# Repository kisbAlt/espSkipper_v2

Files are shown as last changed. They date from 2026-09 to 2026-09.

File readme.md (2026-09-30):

 <div align="center">
  <picture>
    <source media="(prefers-color-scheme: dark)" srcset="./documentation/logo_dark.png">
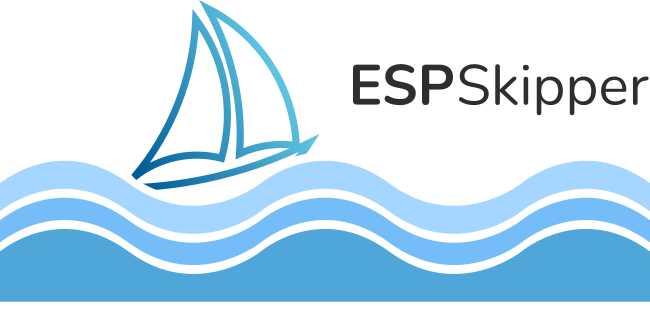
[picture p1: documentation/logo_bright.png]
ESP Skipper logo
    
  </picture>
  <h2 align="center">ESP32 Boat Instrument</h2>
</div>

## ESPSkipper

ESP32 based, open source, low cost boat instrumentation to replace proprietary marine systems.

## Features

- GPS based speed display
- Dynamic multi-function display showing real-time metrics
- Using ST7306 300x400 reflective for good outdoors visibility with custom illumination
- Multi language support
- Configuration through settings page
- Open Echo integration, supports depth readings from the TUSS4470 shield through serial connection
- Rugged 3D printed weather-resistant housing
- Reading water temp thermistors from analog transducers

## Tech Stack

**ESP32:** C++, PlatformIO, Arduino Platform, KiCad  

## Custom PCB

You can find the custom PCB files for KiCad in the hardware folder.

<div align="center" style="display: flex; justify-content: center; align-items: center; gap: 16px; flex-wrap: wrap;">
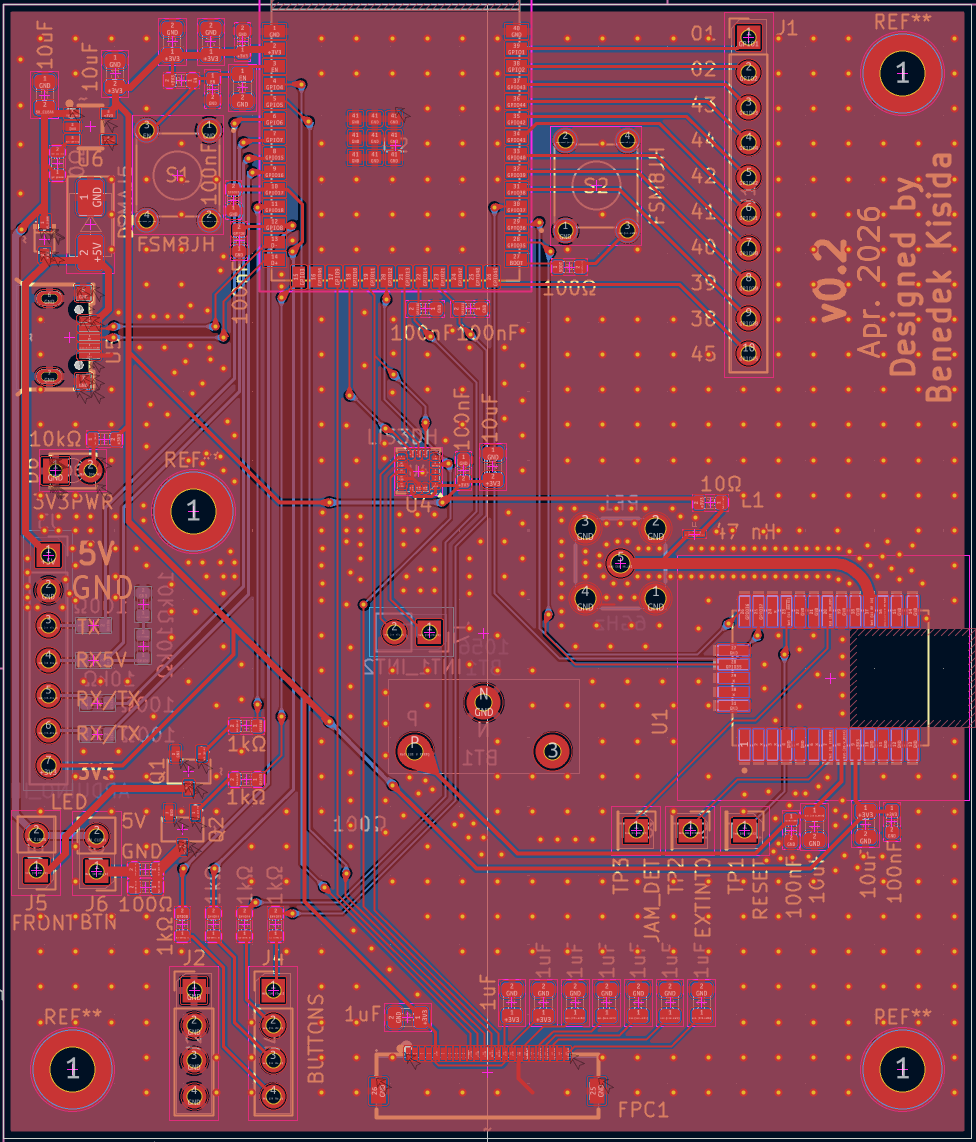
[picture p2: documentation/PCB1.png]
PCB front view
  
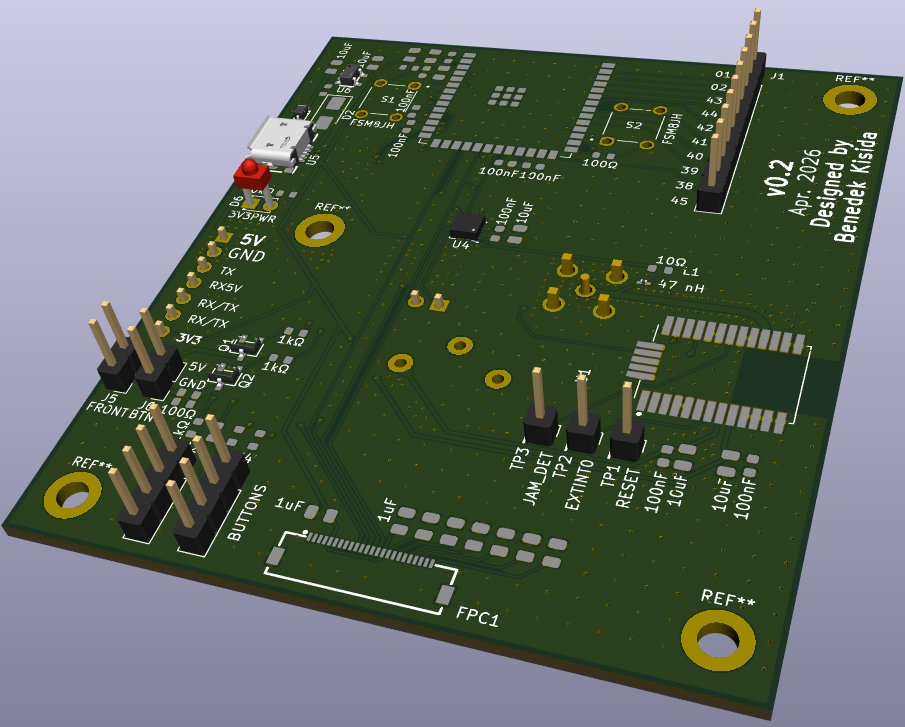
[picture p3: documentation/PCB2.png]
PCB rear view
  
</div>

### ESP32-S3 pinout:

| Module | Signal | GPIO | Notes |
|---|---|---:|---|
| Display / LIS3DH | LCD_SCLK / SPC | GPIO12 | Shared clock for both devices |
| Display / LIS3DH | LCD_SDI / SDO / MOSI | GPIO11 | Shared data output |
| Display / LIS3DH | SDI / MISO | GPIO13 | Shared data input; ignored for LCD |
| LIS3DH | CS | GPIO10 | Dedicated chip select for device 1 |
| Display (PCB variant) | LCD_RES | GPIO4 | Alternate board mapping |
| Display (PCB variant) | LCD_D/C | GPIO9 | Alternate board mapping |
| Display (PCB variant) | LCD_CS | GPIO5 | Alternate board mapping |
| Display (PCB variant) | LCD_SCLK | GPIO12 | Alternate board mapping |
| Display (PCB variant) | LCD_SDI | GPIO11 | Alternate board mapping |
| LIS3DH (PCB variant) | SDO | GPIO13 | Alternate board mapping |
| LIS3DH (PCB variant) | SDI | GPIO11 | Alternate board mapping |
| LIS3DH (PCB variant) | SPC | GPIO12 | Alternate board mapping |
| LIS3DH (PCB variant) | CS | GPIO10 | Alternate board mapping |
| GNSS (L96-M33) | RX0 | GPIO36 | GPS receiver input |
| GNSS (L96-M33) | TX0 | GPIO37 | GPS receiver output |
| GNSS (L96-M33) | FORCE_ON | GPIO35 | Module power control |
| Serial | TX1 | GPIO6 | Serial port 1 output |
| Serial | RX1 | GPIO7 | Serial port 1 input |
| Serial | TX2 | GPIO15 | Serial port 2 output |
| Serial | RX2 | GPIO16 | Serial port 2 input |
| Buttons | BTN1 | GPIO21 | Front panel button |
| Buttons | BTN2 | GPIO14 | Front panel button |
| Buttons | BTN3 | GPIO3 | Front panel button |
| Buttons | BTN4 | GPIO8 | Front panel button |

## Instrument housing

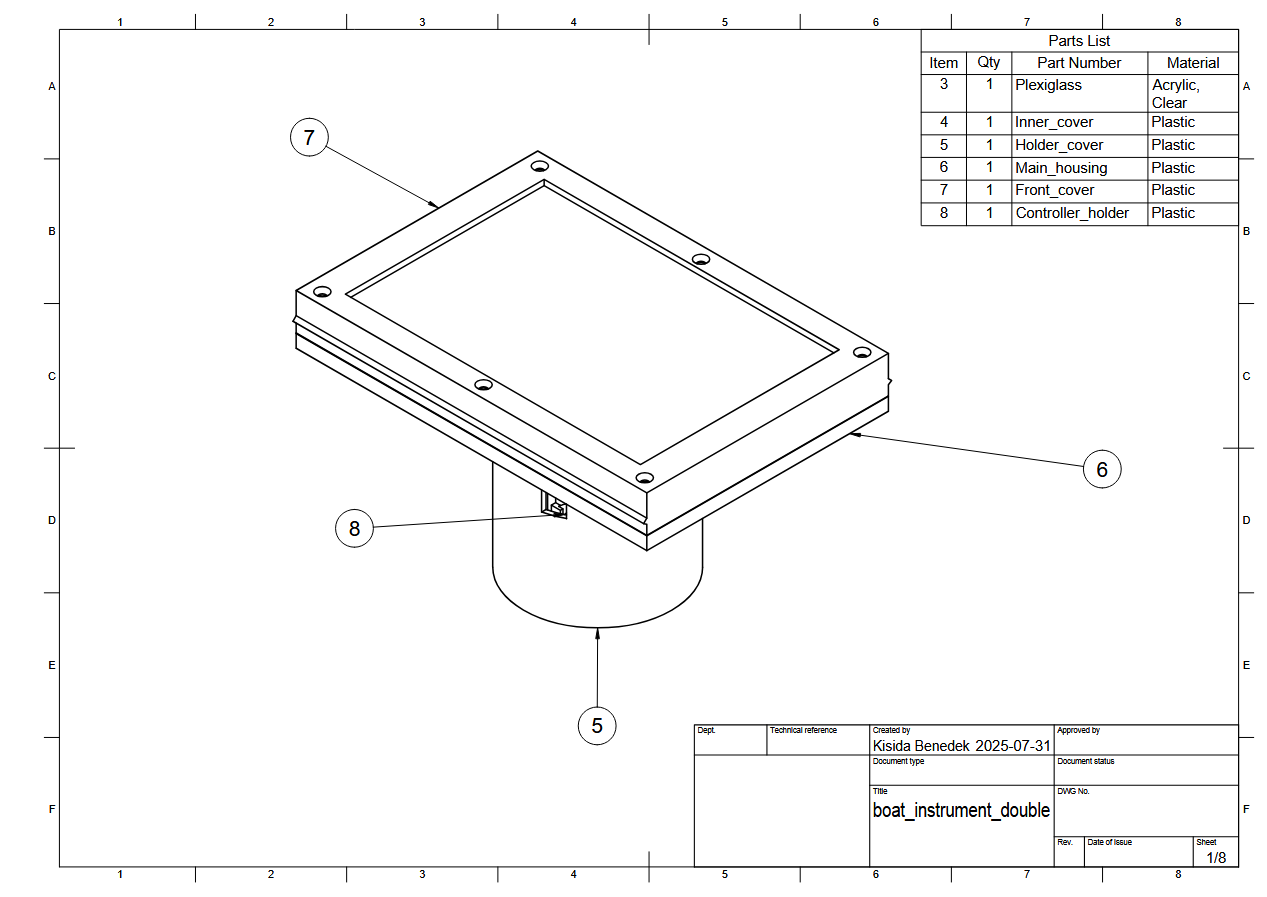
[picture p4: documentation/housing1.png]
Housing1

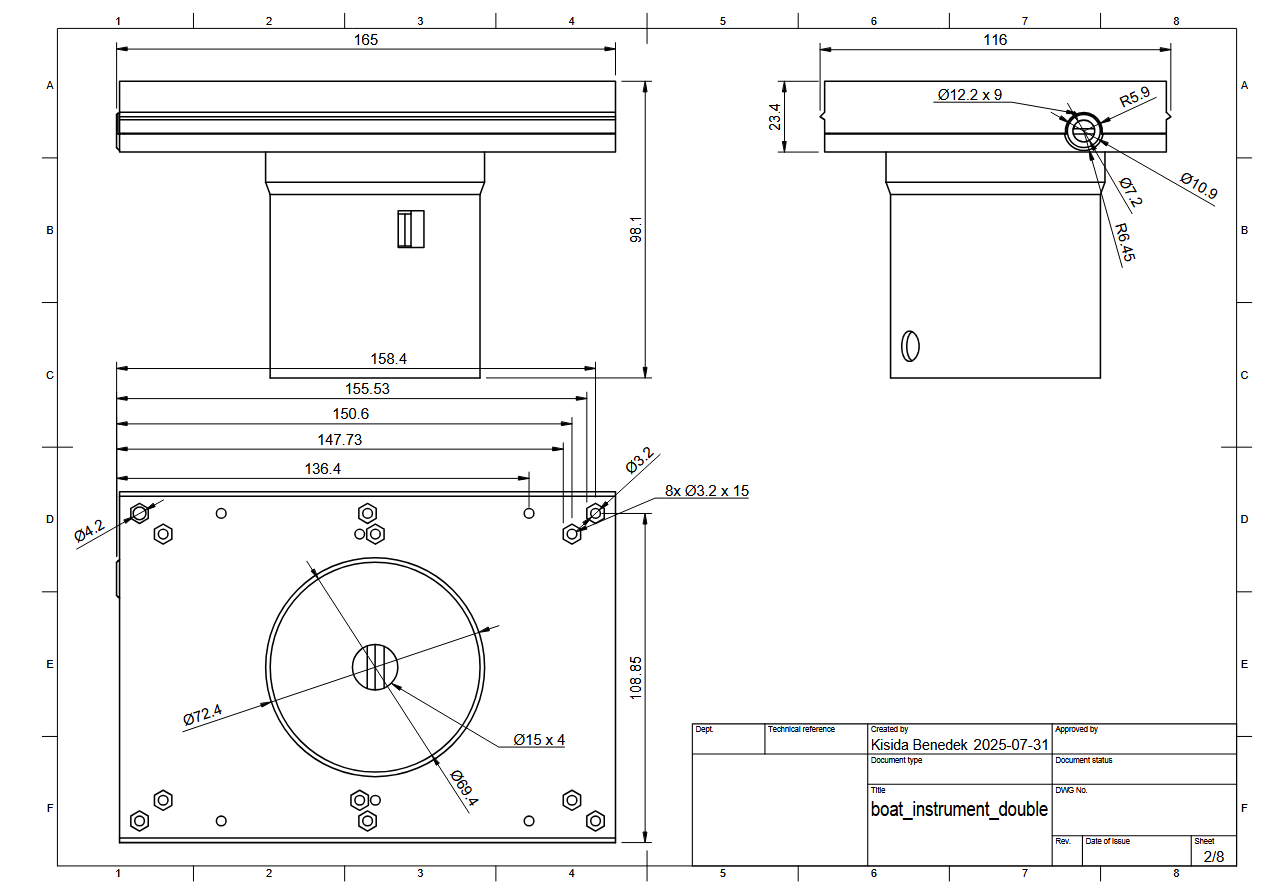
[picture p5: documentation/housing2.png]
Housing2


## PCB Bill of Materials (BOM)

| Ref | Qty | Value | Notes |
|---|---:|---|---|
| U2 | 1 | ESP32-S3-WROOM-1 | Main MCU |
| U1 | 1 | L96-M33 | GNSS module |
| U4 | 1 | LIS3DH | Accelerometer |
| U5 | 1 | - | Micro USB connector |
| U6 | 1 | - | 3.3V regulator |
| BT1 | 1 | 1056 | Battery holder |
| RF1 | 1 | 6GHz | SMA antenna connector |
| FPC1 | 1 | - | Flex cable connector |
| S1, S2 | 2 | FSM8JH | Tactile switches |
| J1 | 1 | Conn_01x10_Pin | 10-pin header |
| J2, J4 | 2 | Conn_01x04_Pin | 4-pin header |
| J3 | 1 | ARDUINO_IN | Arduino interface header |
| J5, J6 | 2 | Conn_01x02_Pin | 2-pin header |
| J7 | 1 | INT1_INT2 | Interrupt header |
| D2 | 1 | SMAJ5 | TVS diode |
| D1 | 1 | - | Schottky diode |
| D6 | 1 | 3V3PWR | 3.3V power LED |
| Q1, Q2 | 2 | - | S8050 transistor pair |
| L1 | 1 | 47 nH | Inductor |
| C1, C2, C3, C4, C16, C18, C20 | 7 | 10uF | Decoupling capacitor |
| C6, C22, C23, C24, C25, C26, C27, C28, C29 | 9 | 1uF | Filter / bulk capacitor |
| C5, C7, C8, C9, C10, C11, C17, C19, C21 | 9 | 100nF | Decoupling capacitor |
| R1, R7, R8, R9, R18, R19 | 6 | 100Ω | Current / pull-up resistor |
| R10, R11, R12, R13, R16, R17 | 6 | 1kΩ | LED / logic resistor |
| R3, R4, R5, R6, R14 | 5 | 10kΩ | Pull-up / bias resistor |
| R2 | 1 | 10Ω | Series resistor |
| R15 | 1 | 0Ω | Link / jumper resistor |
| TP1 | 1 | RESET | Test point |
| TP2 | 1 | EXTINT0 | Test point |
| TP3 | 1 | JAM_DET | Test point |

## Acknowledgements

 - [Open Echo](https://github.com/Neumi/open_echo)
 - [Osptek 4.2" BWR TFT Driver for ESP32-S3 (ST7306)](https://github.com/CaiZiYuan2019/Osptek-4.2-BWR-TFT-Driver-for-ESP32-S3)

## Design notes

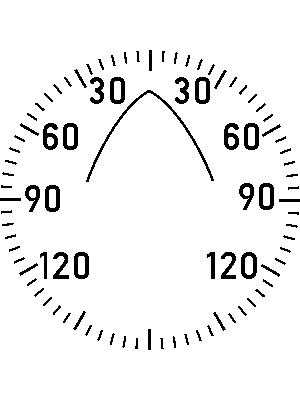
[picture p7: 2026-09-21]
img/wind_gimp.png

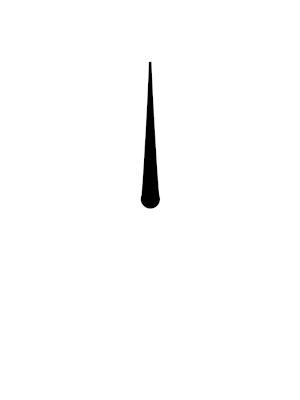
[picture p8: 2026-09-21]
img/wind_hand.png

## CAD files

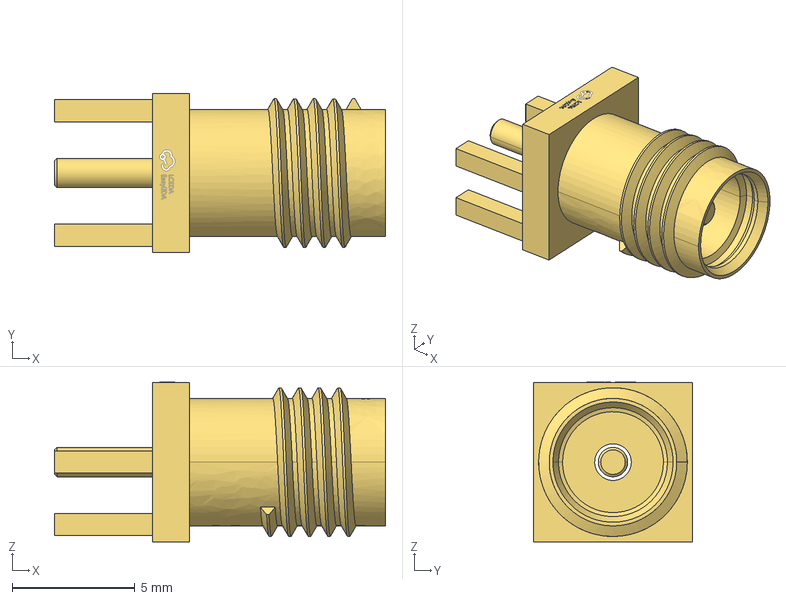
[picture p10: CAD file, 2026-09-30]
hardware/espSkipper2/EASYEDA_MODELS/SMA-SMD_HYCW12-SMAW0863-1365B.step
13.5 x 6.50 x 6.51 mm

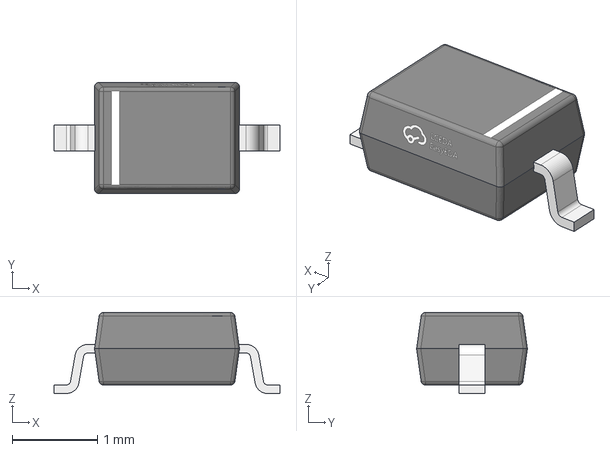
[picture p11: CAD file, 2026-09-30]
hardware/espSkipper2/EASYEDA_MODELS/SOD-323_L1.8-W1.3-LS2.5-RD.step
2.65 x 1.30 x 0.95 mm

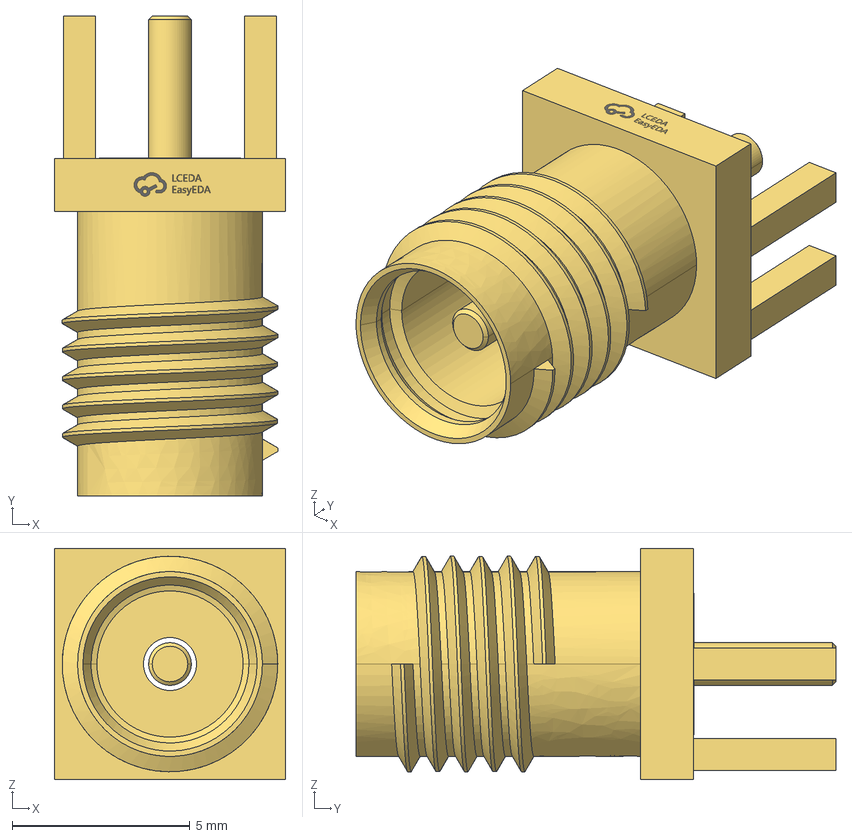
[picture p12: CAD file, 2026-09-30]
hardware/espSkipper2/EASYEDA_MODELS/SMA-SMD_HYCW21-SMAW0865-1350B.step
6.50 x 13.5 x 6.50 mm

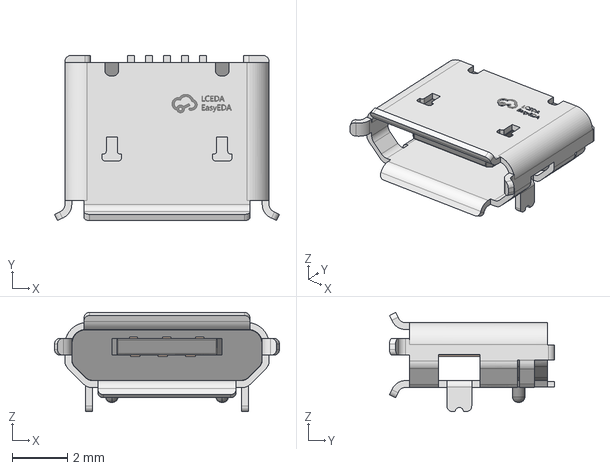
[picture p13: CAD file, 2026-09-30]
hardware/espSkipper2/EASYEDA_MODELS/MICRO-USB-SMD_USB-MR-D-023.step
8.15 x 5.98 x 3.60 mm

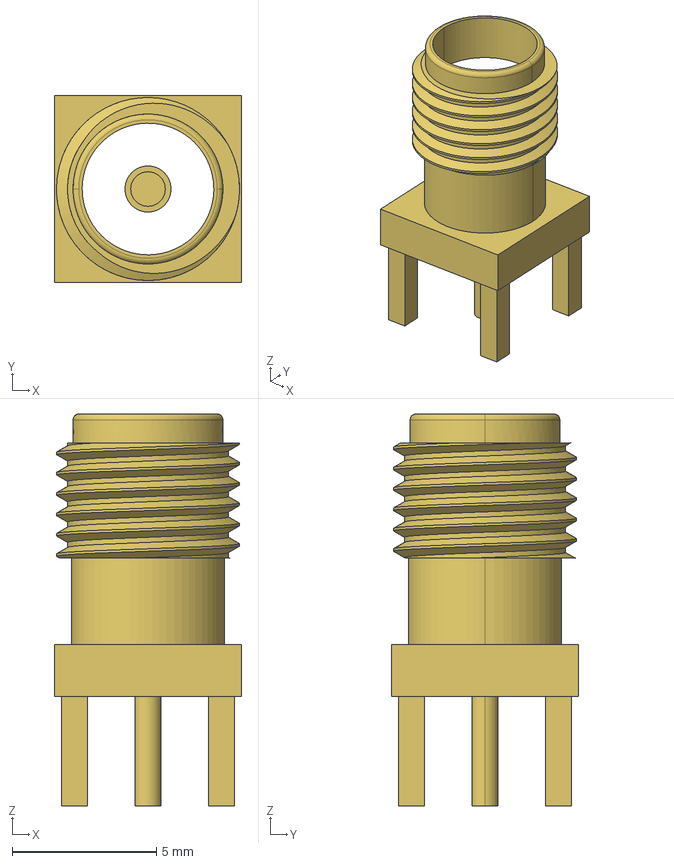
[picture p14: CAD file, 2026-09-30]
hardware/espSkipper2/EASYEDA_MODELS/SMA-TH_5P-L6.5-W6.5-H9.8_BWSMA-KE-Z001.step
6.50 x 6.50 x 13.6 mm

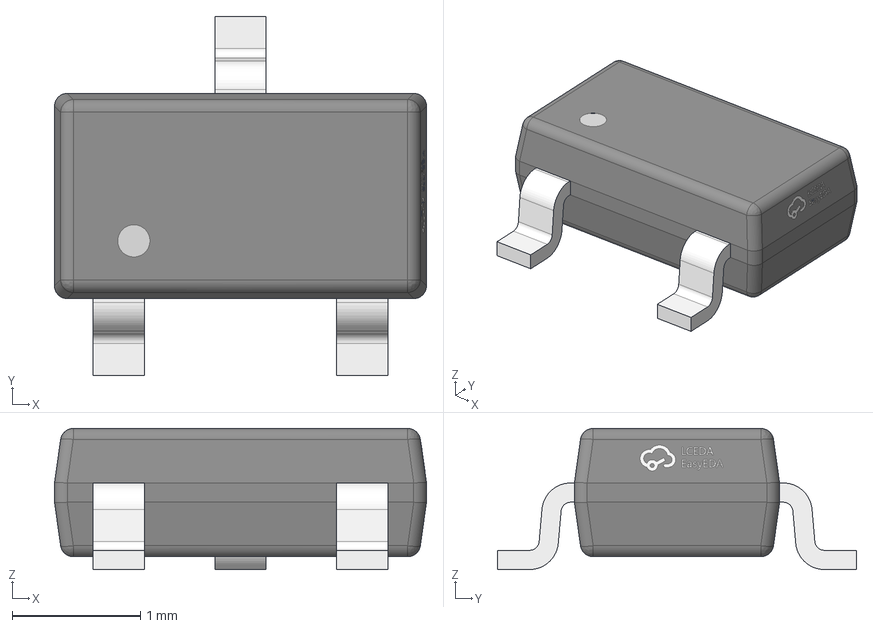
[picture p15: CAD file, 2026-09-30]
hardware/espSkipper2/EASYEDA_MODELS/SOT-23-3L_L2.9-W1.6-H1.1-LS2.8-P0.95.step
2.90 x 2.80 x 1.10 mm

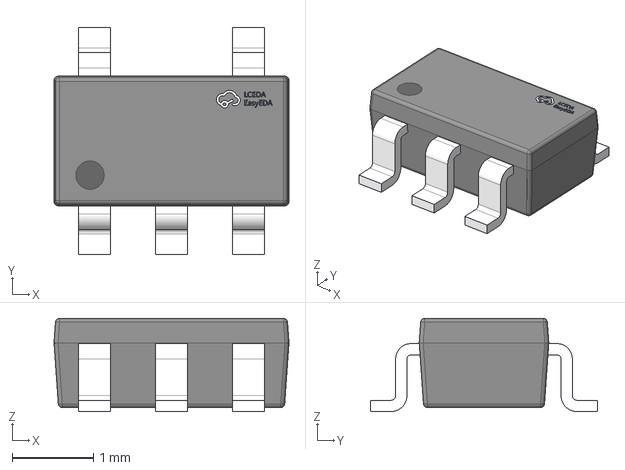
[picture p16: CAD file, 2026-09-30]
hardware/espSkipper2/EASYEDA_MODELS/SOT-23-5_L2.9-W1.6-P0.95-LS2.7-BR.step
2.90 x 2.80 x 1.15 mm

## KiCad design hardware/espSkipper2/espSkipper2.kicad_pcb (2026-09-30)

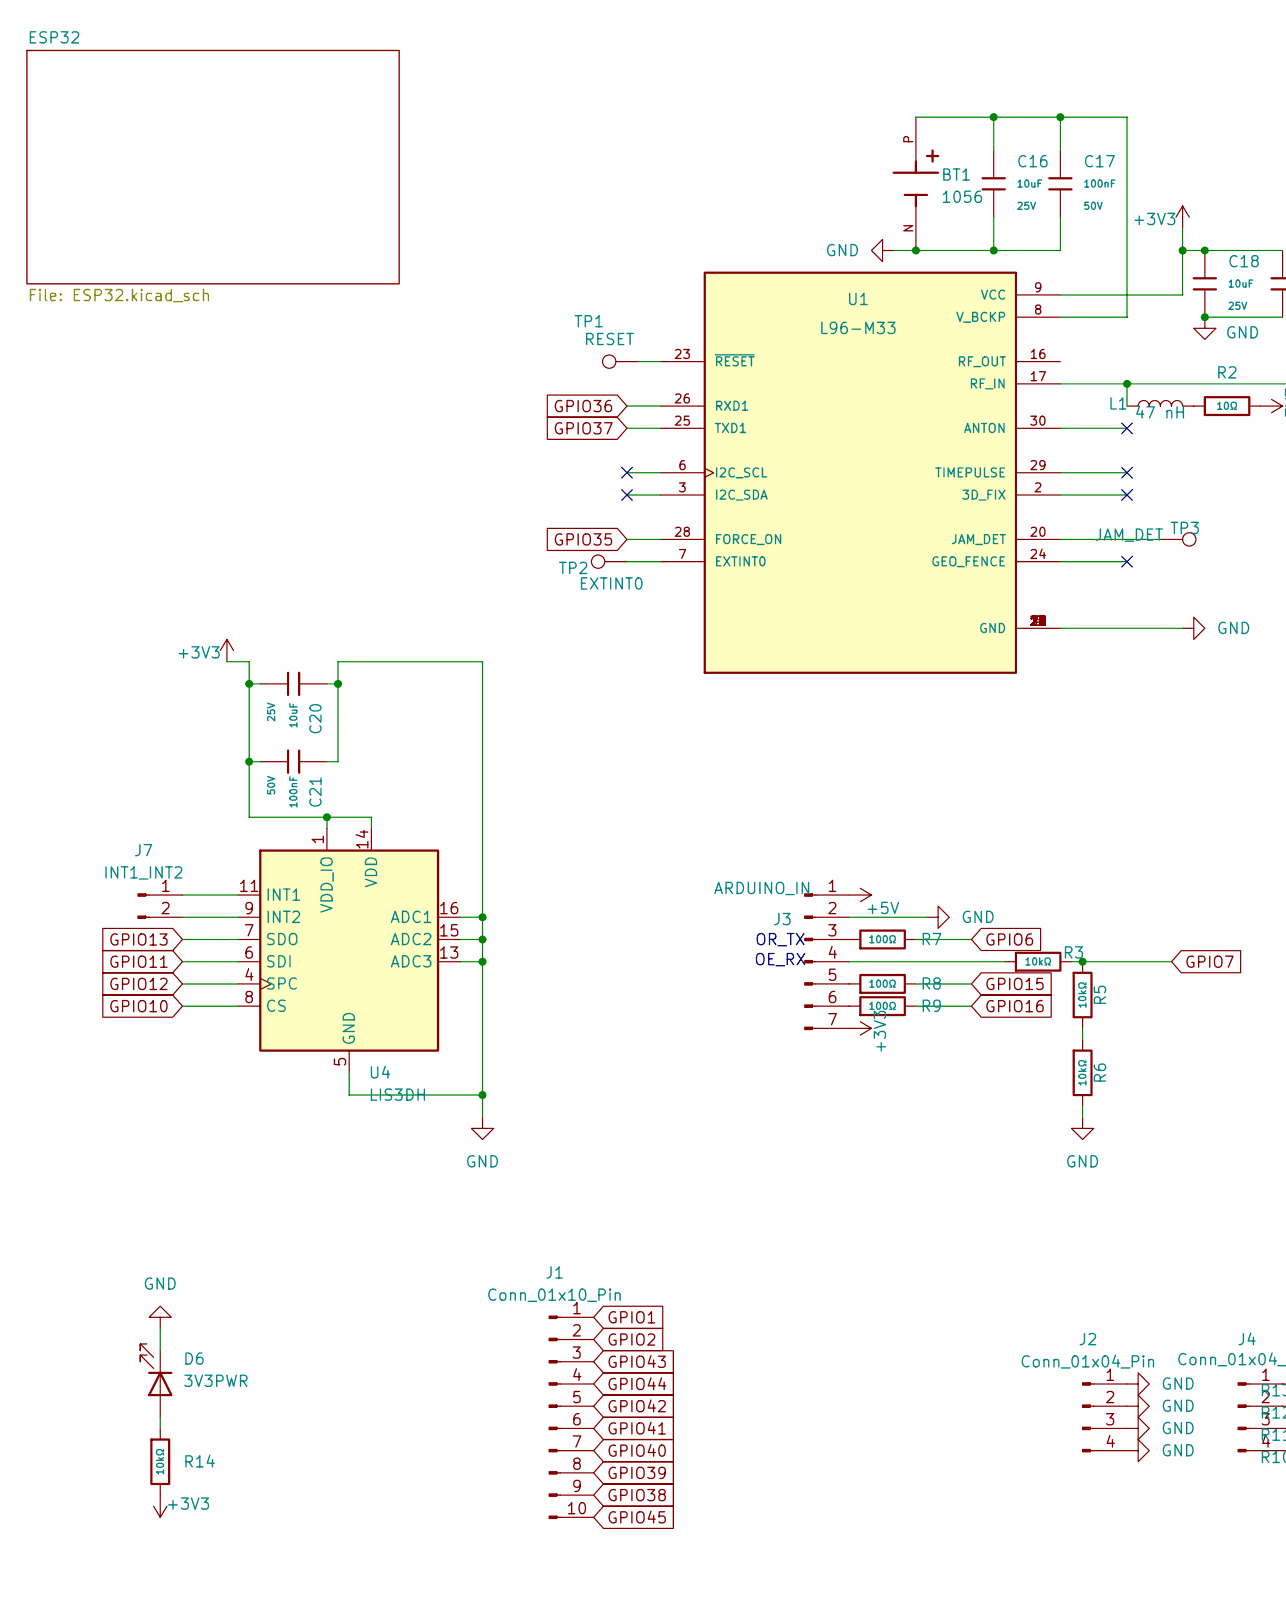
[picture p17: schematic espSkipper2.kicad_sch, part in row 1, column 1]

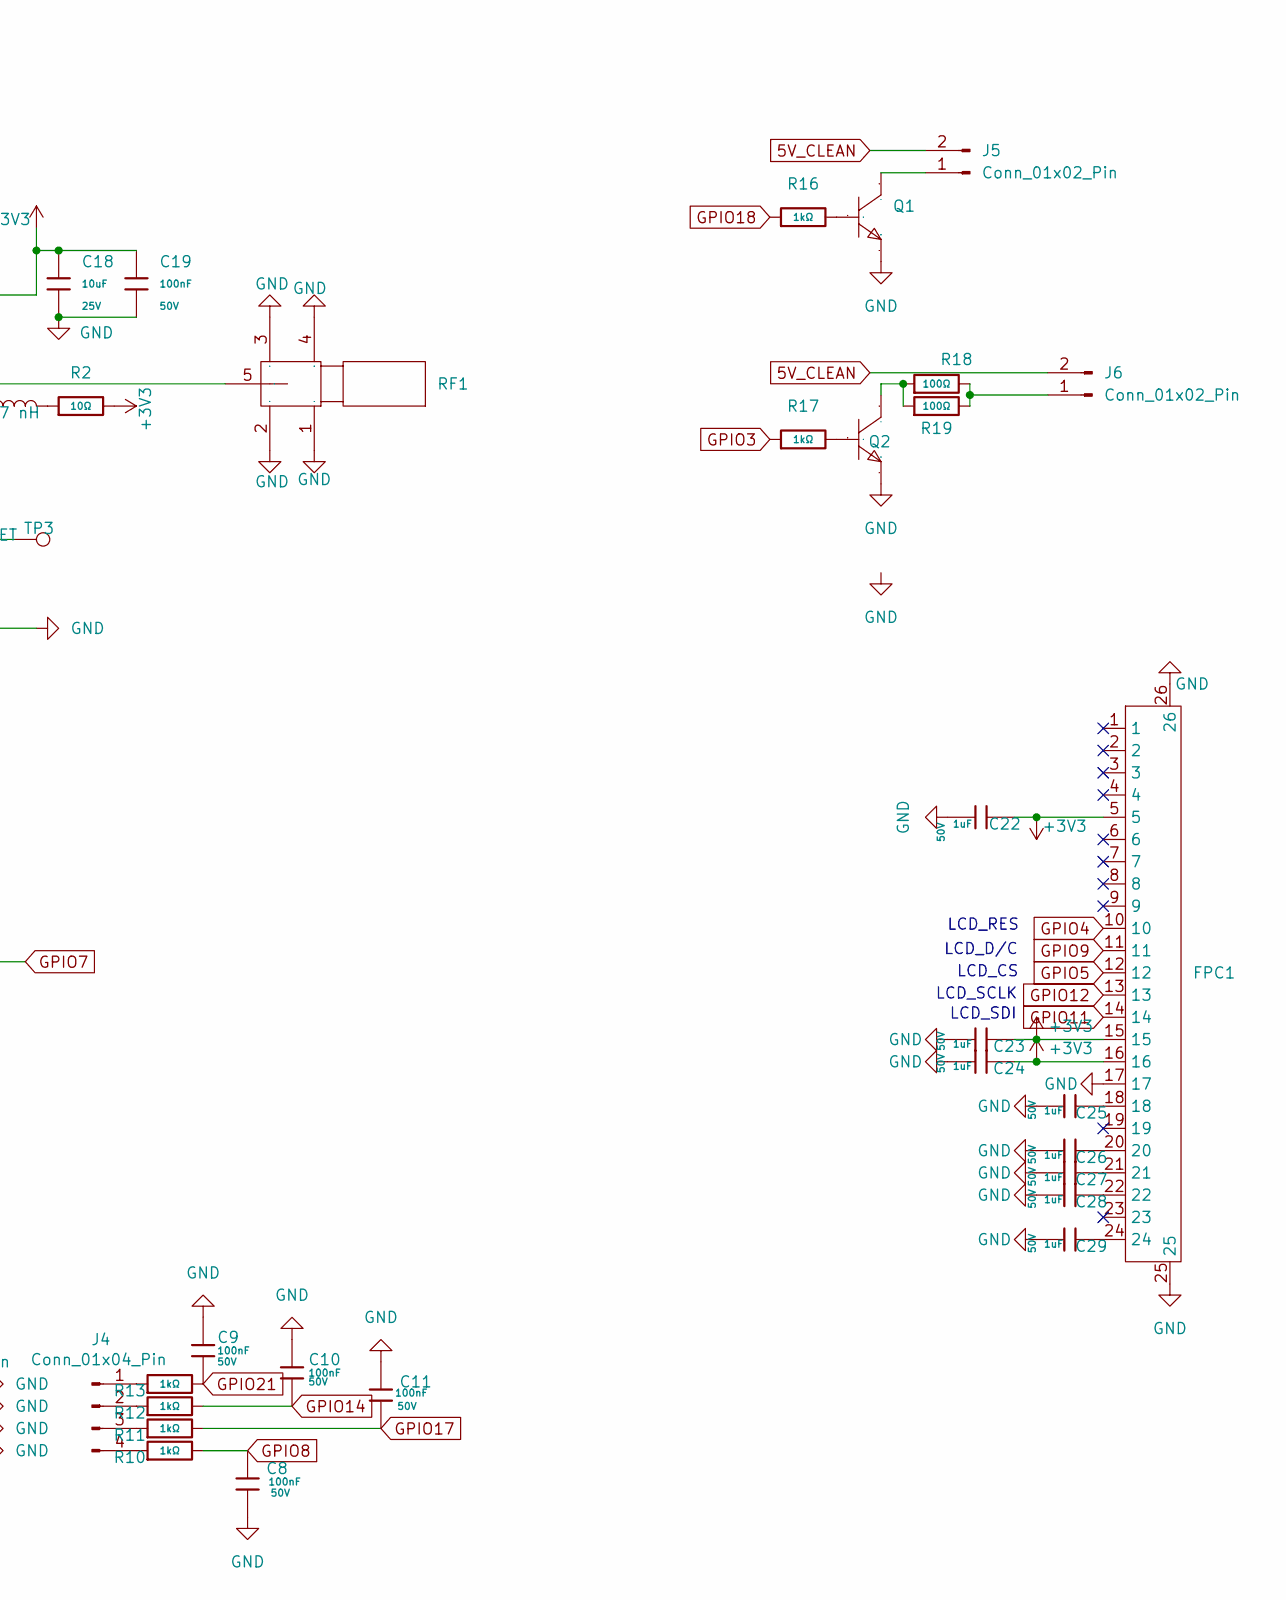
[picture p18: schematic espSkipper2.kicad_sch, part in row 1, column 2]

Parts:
BT1: 1056; BAT_1056; PARTREV D
C8, C9, C10, C11, C17, C19, C21: 100nF; C_0603; Voltage Rated 50V; Tolerance ±10%; Part CC0603KRX7R9BB104; LCSC C14663
C16, C18, C20: 10uF; C_0805; Voltage Rated 25V; Tolerance ±10%; Part CL21A106KAYNNNE; LCSC C15850
C22, C23, C24, C25, C26, C27, C28, C29: 1uF; C_0805; Voltage Rated 50V; Tolerance ±10%; Part CL21B105KBFNNNE; LCSC C28323
D6: 3V3PWR; LED_D1.8mm_W3.3mm_H2.4mm
FPC1: FPC-SMD_FPC24-T1T1-2021-A; Manufacturer Part FPC24-T1T1-2021-A; LCSC Part Name 翻盖式 下接 P数:24P 间距:0.5mm
J1: Conn_01x10_Pin; PinHeader_1x10_P2.54mm_Vertical
J2, J4: Conn_01x04_Pin; PinHeader_1x04_P2.54mm_Vertical
J3: ARDUINO_IN; PinHeader_1x07_P2.54mm_Vertical
J5, J6: Conn_01x02_Pin; PinHeader_1x02_P2.54mm_Vertical
J7: INT1_INT2; PinHeader_1x02_P2.54mm_Vertical
L1: 47 nH; L_0201_0603Metric_Pad0.64x0.40mm_HandSolder
Q1, Q2: SOT-23-3_L2.9-W1.6-P1.90-LS2.8-BR; Manufacturer Part S8050; LCSC Part Name NPN 电流:500mA 电压:25V
R2: 10Ω; R_0603; Overload Voltage (Max) 75V; Tolerance ±1%; Part 0603WAF100JT5E; LCSC C22859
R3, R5, R6, R14: 10kΩ; R_0603; Overload Voltage (Max) 75V; Tolerance ±1%; Part 0603WAF1002T5E; LCSC C25804
R7, R8, R9, R18, R19: 100Ω; R_0603; Overload Voltage (Max) 75V; Tolerance ±1%; Part 0603WAF1000T5E; LCSC C22775
R10, R11, R12, R13, R16, R17: 1kΩ; R_0603; Overload Voltage (Max) 75V; Tolerance ±1%; Part 0603WAF1001T5E; LCSC C21190
RF1: 6GHz; SMA-TH_BWSMA-KE-Z001; Manufacturer Part SMA-KWE/KE-135; LCSC Part Name 内孔 SMA 正脚
TP1: RESET; PinHeader_1x01_P2.54mm_Vertical
TP2: EXTINT0; PinHeader_1x01_P2.54mm_Vertical
TP3: JAM_DET; PinHeader_1x01_P2.54mm_Vertical
U1: L96-M33; XCVR_L96-M33
U4: LIS3DH; LGA-16_3x3mm_P0.5mm_LayoutBorder3x5y

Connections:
5V_CLEAN: J5.2, J6.2; also elsewhere on the board
+3V3: C18.1, C19.1, C20.2, C21.2, C22.1, C23.1, C24.1, FPC1.5, FPC1.15, FPC1.16, J3.7, R2.2, R14.2, U1.9 (VCC), U4.1 (VDD_IO), U4.14 (VDD); also elsewhere on the board
+5V: J3.1; also elsewhere on the board
GND: BT1.N, C8.1, C9.1, C10.1, C11.1, C16.2, C17.2, C18.2, C19.2, C20.1, C21.1, C22.2, C23.2, C24.2, C25.2, C26.2, C27.2, C28.2, C29.2, D6.1 (K), FPC1.17, FPC1.25, FPC1.26, J2.1, J2.2, J2.3, J2.4, J3.2, Q1.2 (E), Q2.2 (E), R6.2, RF1.1, RF1.2, RF1.3, RF1.4, U1.4 (GND), U1.5 (GND), U1.10 (GND), U1.11 (GND), U1.12 (GND), U1.13 (GND), U1.14 (GND), U1.15 (GND), U1.18 (GND), U1.19 (GND), U1.21 (GND), U1.22 (GND), U1.27 (GND), U1.31 (GND), U4.5 (GND), U4.10 (GND), U4.12 (GND), U4.13 (ADC3), U4.15 (ADC2), U4.16 (ADC1); also elsewhere on the board
GPIO1: J1.1; also elsewhere on the board
GPIO2: J1.2; also elsewhere on the board
GPIO3: R17.1; also elsewhere on the board
GPIO4: FPC1.10; also elsewhere on the board
GPIO5: FPC1.12; also elsewhere on the board
GPIO6: R7.2; also elsewhere on the board
GPIO7: R3.2, R5.1; also elsewhere on the board
GPIO8: C8.2, R10.2; also elsewhere on the board
GPIO9: FPC1.11; also elsewhere on the board
GPIO10: U4.8 (CS); also elsewhere on the board
GPIO11: FPC1.14, U4.6 (SDI); also elsewhere on the board
GPIO12: FPC1.13, U4.4 (SPC); also elsewhere on the board
GPIO13: U4.7 (SDO); also elsewhere on the board
GPIO14: C10.2, R12.2; also elsewhere on the board
GPIO15: R8.2; also elsewhere on the board
GPIO16: R9.2; also elsewhere on the board
GPIO17: C11.2, R11.2; also elsewhere on the board
GPIO18: R16.1; also elsewhere on the board
GPIO21: C9.2, R13.2; also elsewhere on the board
GPIO35: U1.28 (FORCE_ON); also elsewhere on the board
GPIO36: U1.26 (RXD1); also elsewhere on the board
GPIO37: U1.25 (TXD1); also elsewhere on the board
GPIO38: J1.9; also elsewhere on the board
GPIO39: J1.8; also elsewhere on the board
GPIO40: J1.7; also elsewhere on the board
GPIO41: J1.6; also elsewhere on the board
GPIO42: J1.5; also elsewhere on the board
GPIO43: J1.3; also elsewhere on the board
GPIO44: J1.4; also elsewhere on the board
GPIO45: J1.10; also elsewhere on the board
unnamed: C25.1, FPC1.18
unnamed: C26.1, FPC1.20
unnamed: C27.1, FPC1.21
unnamed: C28.1, FPC1.22
unnamed: C29.1, FPC1.24
unnamed: D6.2 (A), R14.1
unnamed: J3.3, R7.1
unnamed: J3.4, R3.1
unnamed: J3.5, R8.1
unnamed: J3.6, R9.1
unnamed: J4.1, R13.1
unnamed: J4.2, R12.1
unnamed: J4.3, R11.1
unnamed: J4.4, R10.1
unnamed: J5.1, Q1.3 (C)
unnamed: J6.1, R18.2, R19.2
unnamed: J7.1, U4.11 (INT1)
unnamed: J7.2, U4.9 (INT2)
unnamed: L1.2, R2.1
unnamed: Q1.1 (B), R16.2
unnamed: Q2.1 (B), R17.2
unnamed: Q2.3 (C), R18.1, R19.1
unnamed: R5.2, R6.1
unnamed: TP2.1, U1.7 (EXTINT0)
unnamed: TP3.1, U1.20 (JAM_DET)
unnamed: L1.1, RF1.5, U1.17 (RF_IN)
unnamed: BT1.P, C16.1, C17.1, U1.8 (V_BCKP)
unnamed: TP1.1, U1.23 (~RESET)

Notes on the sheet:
LCD_RES
LCD_SCLK
OR_TX
LCD_SDI
OE_RX
LCD_D/C
LCD_CS

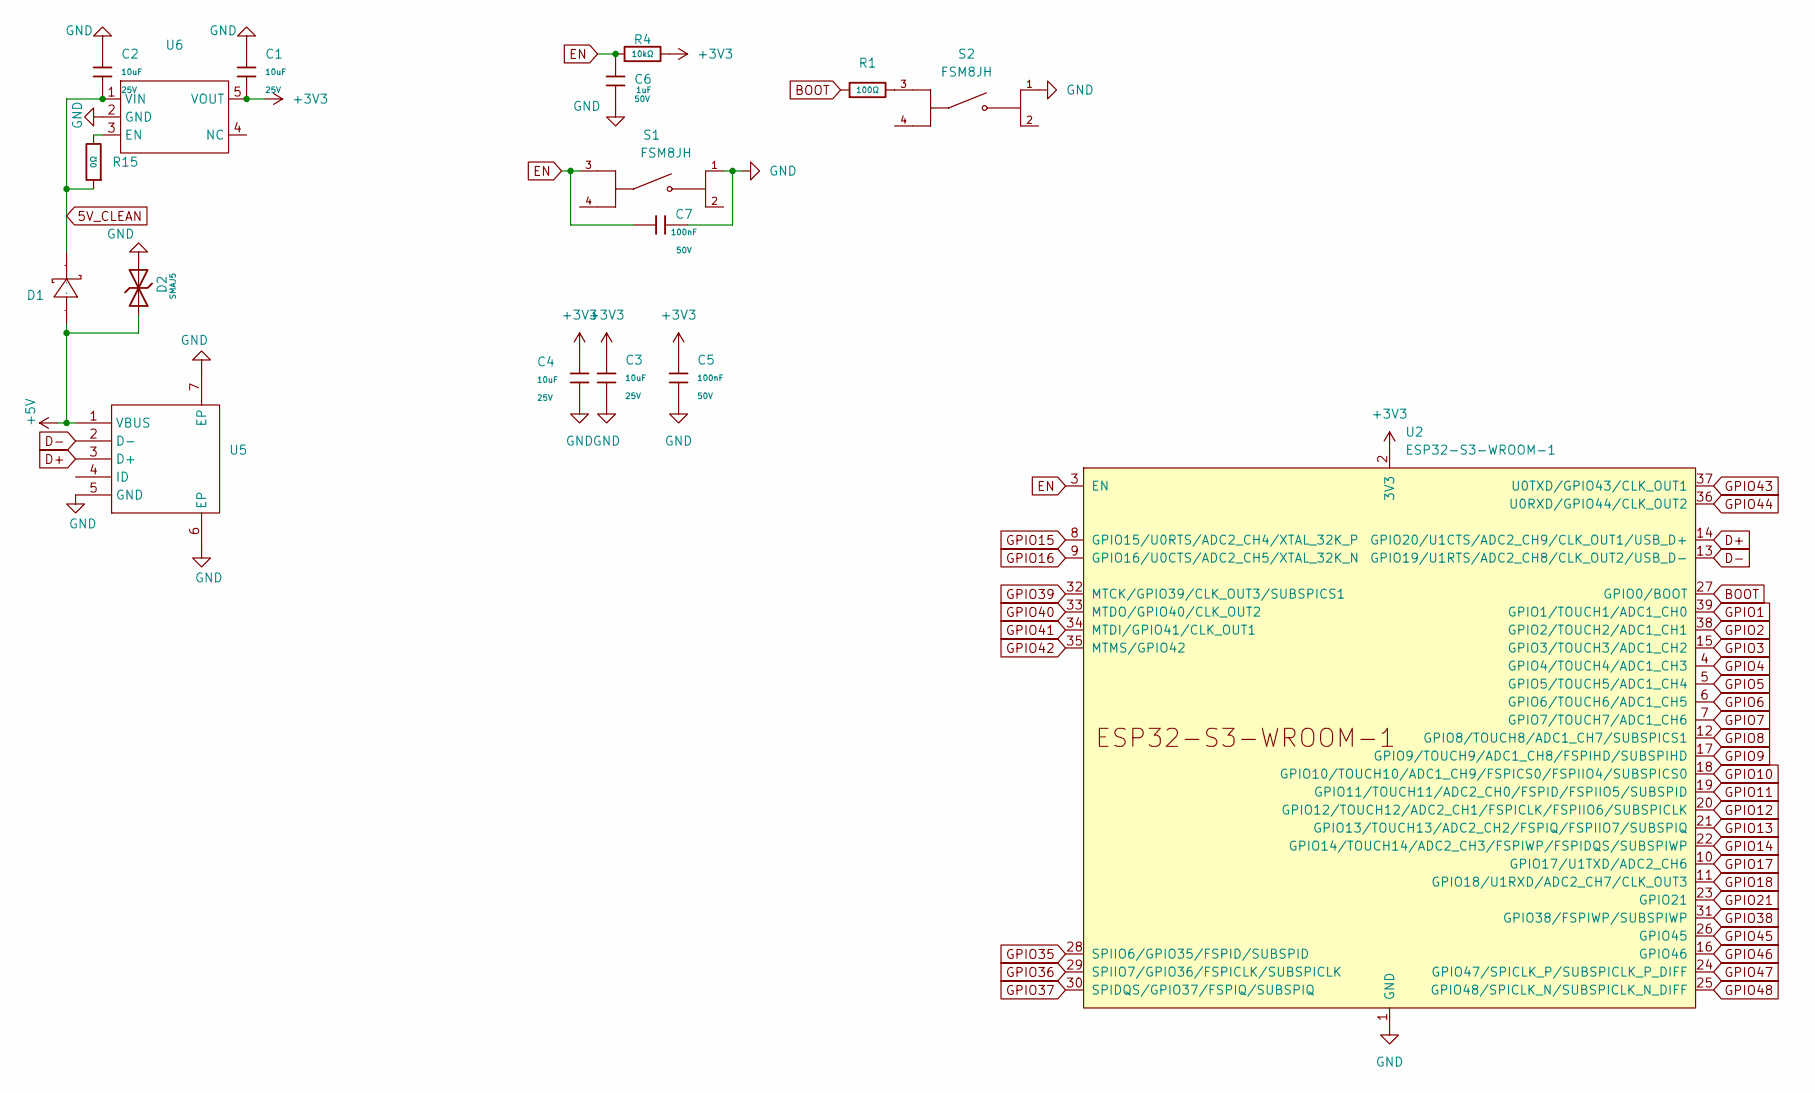
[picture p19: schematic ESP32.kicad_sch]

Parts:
C1, C2, C3, C4: 10uF; C_0805; Voltage Rated 25V; Tolerance ±10%; Part CL21A106KAYNNNE; LCSC C15850
C5, C7: 100nF; C_0603; Voltage Rated 50V; Tolerance ±10%; Part CC0603KRX7R9BB104; LCSC C14663
C6: 1uF; C_0805; Voltage Rated 50V; Tolerance ±10%; Part CL21B105KBFNNNE; LCSC C28323
D1: SOD-323_L1.8-W1.3-LS2.5-RD; Manufacturer Part 1N5819WS; LCSC Part Name 电压:40V 电流:1A
D2: SMAJ5; D_SMA; Part SMAJ5.0CA; LCSC C19077524
R1: 100Ω; R_0603; Overload Voltage (Max) 75V; Tolerance ±1%; Part 0603WAF1000T5E; LCSC C22775
R4: 10kΩ; R_0603; Overload Voltage (Max) 75V; Tolerance ±1%; Part 0603WAF1002T5E; LCSC C25804
R15: 0Ω; R_0603; Overload Voltage (Max) 75V; Tolerance ±1%; Part 0603WAF0000T5E; LCSC C21189
S1, S2: FSM8JH; SW_FSM8JH; PARTREV 8-1773450-9
U2: ESP32-S3-WROOM-1
U5: MICRO-USB-SMD_USB-MR-D-023; Manufacturer Part USB-MR-D-023; LCSC Part Name Micro-B 母 卧贴
U6: SOT-23-5_L2.9-W1.6-P0.95-LS2.7-BR; Manufacturer Part AP2112K-3.3TRG1(MS); LCSC Part Name AP2112K-3.3TRG1(MS)

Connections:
5V_CLEAN: C2.2, D1.1 (K), R15.1, U6.1 (VIN); also elsewhere on the board
+3V3: C1.2, C3.1, C4.1, C5.1, R4.2, U2.2 (3V3), U6.5 (VOUT); also elsewhere on the board
+5V: D1.2 (A), D2.2, U5.1 (VBUS); also elsewhere on the board
BOOT: R1.1, U2.27 (GPIO0/BOOT)
D+: U2.14 (GPIO20/U1CTS/ADC2_CH9/CLK_OUT1/USB_D+), U5.3 (D+)
D-: U2.13 (GPIO19/U1RTS/ADC2_CH8/CLK_OUT2/USB_D-), U5.2 (D-)
EN: C6.1, C7.1, R4.1, S1.3, U2.3 (EN)
GND: C1.1, C2.1, C3.2, C4.2, C5.2, C6.2, C7.2, D2.1, S1.1, S2.1, U2.1 (GND), U2.40 (GND), U2.41 (GND), U5.5 (GND), U5.6 (EP), U5.7 (EP), U6.2 (GND); also elsewhere on the board
GPIO1: U2.39 (GPIO1/TOUCH1/ADC1_CH0); also elsewhere on the board
GPIO2: U2.38 (GPIO2/TOUCH2/ADC1_CH1); also elsewhere on the board
GPIO3: U2.15 (GPIO3/TOUCH3/ADC1_CH2); also elsewhere on the board
GPIO4: U2.4 (GPIO4/TOUCH4/ADC1_CH3); also elsewhere on the board
GPIO5: U2.5 (GPIO5/TOUCH5/ADC1_CH4); also elsewhere on the board
GPIO6: U2.6 (GPIO6/TOUCH6/ADC1_CH5); also elsewhere on the board
GPIO7: U2.7 (GPIO7/TOUCH7/ADC1_CH6); also elsewhere on the board
GPIO8: U2.12 (GPIO8/TOUCH8/ADC1_CH7/SUBSPICS1); also elsewhere on the board
GPIO9: U2.17 (GPIO9/TOUCH9/ADC1_CH8/FSPIHD/SUBSPIHD); also elsewhere on the board
GPIO10: U2.18 (GPIO10/TOUCH10/ADC1_CH9/FSPICS0/FSPIIO4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); also elsewhere on the board
GPIO11: U2.19 (GPIO11/TOUCH11/ADC2_CH0/FSPID/FSPIIO5/S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); also elsewhere on the board
GPIO12: U2.20 (GPIO12/TOUCH12/ADC2_CH1/FSPICLK/FSPIIO6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); also elsewhere on the board
GPIO13: U2.21 (GPIO13/TOUCH13/ADC2_CH2/FSPIQ/FSPIIO7/S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); also elsewhere on the board
GPIO14: U2.22 (GPIO14/TOUCH14/ADC2_CH3/FSPIWP/FSPIDQS/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); also elsewhere on the board
GPIO15: U2.8 (GPIO15/U0RTS/ADC2_CH4/XTAL_32K_P); also elsewhere on the board
GPIO16: U2.9 (GPIO16/U0CTS/ADC2_CH5/XTAL_32K_N); also elsewhere on the board
GPIO17: U2.10 (GPIO17/U1TXD/ADC2_CH6); also elsewhere on the board
GPIO18: U2.11 (GPIO18/U1RXD/ADC2_CH7/CLK_OUT3); also elsewhere on the board
GPIO21: U2.23 (GPIO21); also elsewhere on the board
GPIO35: U2.28 (SPIIO6/GPIO35/FSPID/SUBSPID); also elsewhere on the board
GPIO36: U2.29 (SPIIO7/GPIO36/FSPICLK/SUBSPICLK); also elsewhere on the board
GPIO37: U2.30 (SPIDQS/GPIO37/FSPIQ/SUBSPIQ); also elsewhere on the board
GPIO38: U2.31 (GPIO38/FSPIWP/SUBSPIWP); also elsewhere on the board
GPIO39: U2.32 (MTCK/GPIO39/CLK_OUT3/SUBSPICS1); also elsewhere on the board
GPIO40: U2.33 (MTDO/GPIO40/CLK_OUT2); also elsewhere on the board
GPIO41: U2.34 (MTDI/GPIO41/CLK_OUT1); also elsewhere on the board
GPIO42: U2.35 (MTMS/GPIO42); also elsewhere on the board
GPIO43: U2.37 (U0TXD/GPIO43/CLK_OUT1); also elsewhere on the board
GPIO44: U2.36 (U0RXD/GPIO44/CLK_OUT2); also elsewhere on the board
GPIO45: U2.26 (GPIO45); also elsewhere on the board
GPIO46: U2.16 (GPIO46)
GPIO47: U2.24 (GPIO47/SPICLK_P/SUBSPICLK_P_DIFF)
GPIO48: U2.25 (GPIO48/SPICLK_N/SUBSPICLK_N_DIFF)
unnamed: R1.2, S2.3
unnamed: R15.2, U6.3 (EN)

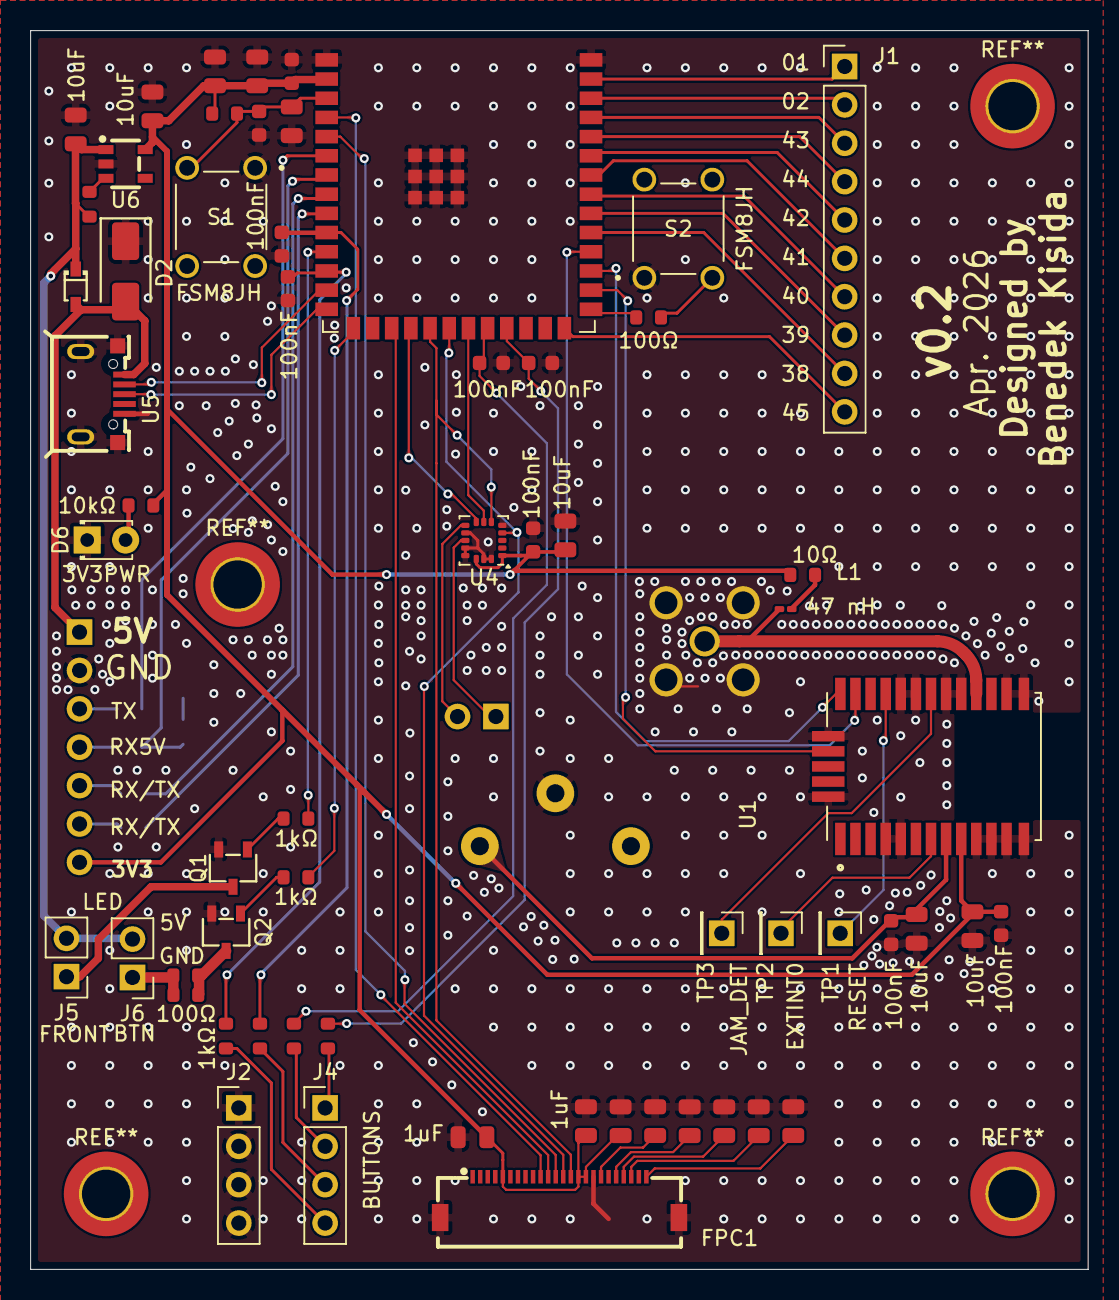
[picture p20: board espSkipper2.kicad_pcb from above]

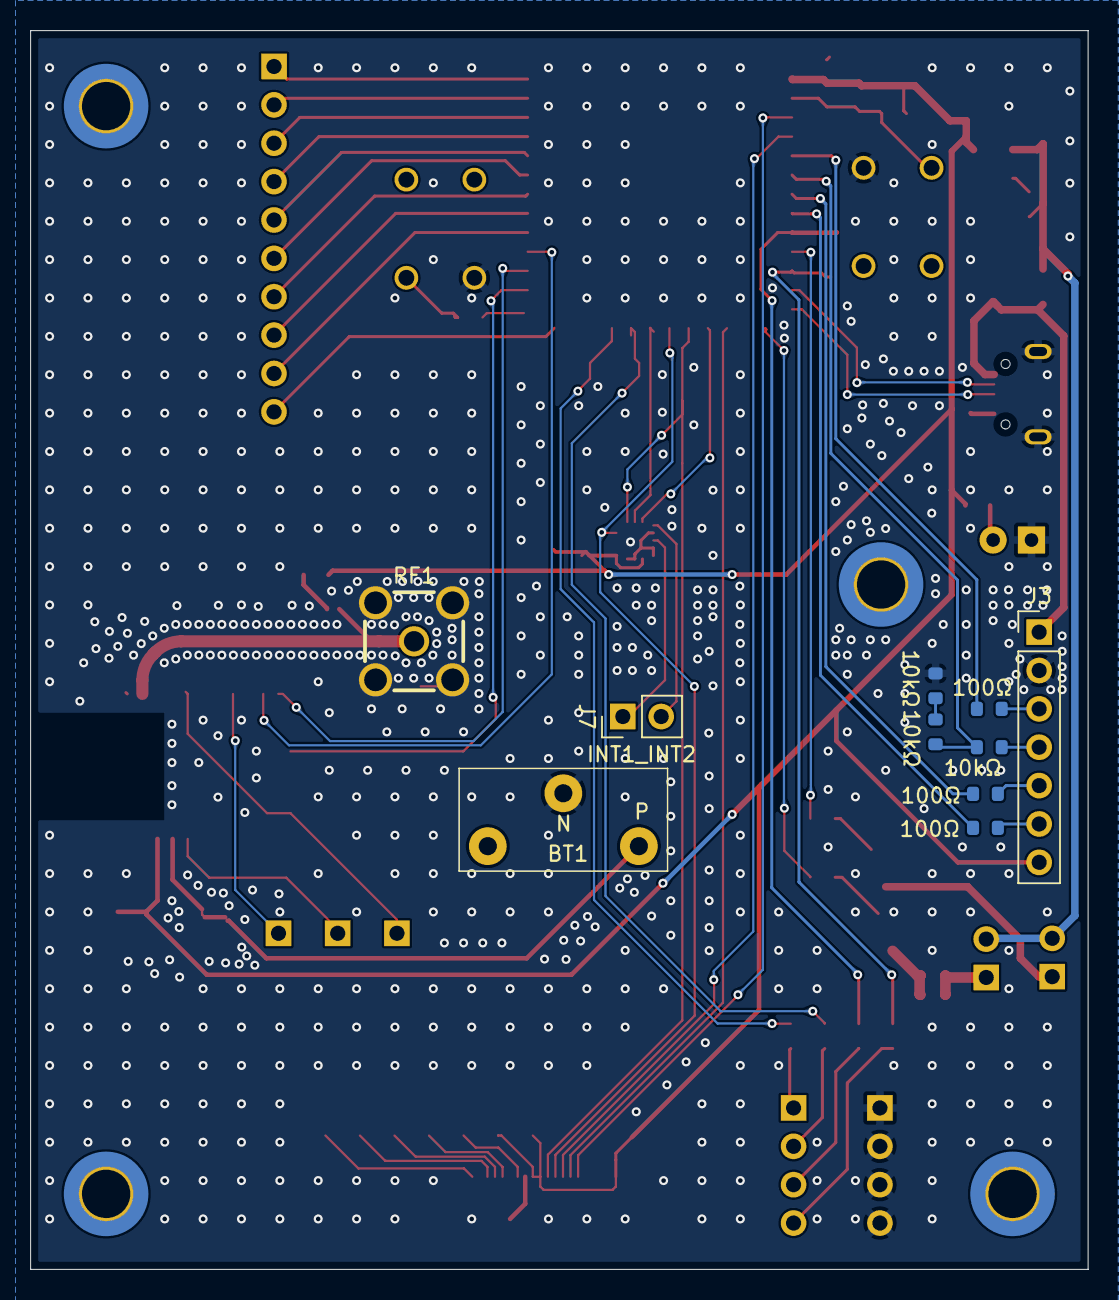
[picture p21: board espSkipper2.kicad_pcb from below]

Board: 2 copper layers, 70.0 x 82.0 mm, 70 parts (10 on the bottom side), 68 nets.

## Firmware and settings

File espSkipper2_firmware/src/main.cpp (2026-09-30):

#include <Arduino.h>
#include "display/displayHandler.hpp"
#include "accelerometerHandler.hpp"
#include "gpsHandler.hpp"
#include "Wire.h"
#include "SPI.h"
#include "display/displayUtils.hpp"
#include "instrumentDataModel.hpp"
#include "stringTranslator.hpp"
#include "buttonHandler.hpp"
#include "ledHandler.hpp"
#include "settingsHandler.hpp"
#include "settingsDisplay.hpp"
#include "depthHandler.hpp"
#include "windHandler.hpp"

Settings settings{};

InstrumentDataModel instrumentDataModel(settings);
DisplayHandler displayHandler(instrumentDataModel, settings);
AccelerometerHandler accelerometerHandler(instrumentDataModel);
GpsHandler gpsHandler(instrumentDataModel);
SettingsDisplay settingsDisplay(settings, displayHandler);
DepthHandler depthHandler(settings, instrumentDataModel);
WindHandler windHandler(instrumentDataModel);

ButtonHandler btn0(8);
ButtonHandler btn1(17);
ButtonHandler btn2(14);
ButtonHandler btn3(21);
QueueHandle_t buttonEventQueue;

void postButtonEvent(const ButtonName btnName, const ButtonEvent event)
{
    const ButtonMessage message{btnName, event};
    xQueueSend(buttonEventQueue, &message, 0);
}

void handleButtonEvent(const ButtonName btnName, const ButtonEvent event);

void globalButtonTask(void* arg) {
    while (true) {
        btn0.Process();
        btn1.Process();
        btn2.Process();
        btn3.Process();
        vTaskDelay(pdMS_TO_TICKS(5));
    }
}

LedHandler btnLed(3, []() { return settings.GetValue<bool>(SettingsKey::BtnLedEnabled); }, []() { return settings.GetValue<uint8_t>(SettingsKey::BtnBrightness); }, 0);
LedHandler lcdLed(18, []() { return settings.GetValue<bool>(SettingsKey::LCDLedEnabled); }, []() { return settings.GetValue<uint8_t>(SettingsKey::LCDBrightness); }, 1);

enum class AppState
{
    MAIN_SCREEN,
    SETTINGS_SCREEN
};
AppState currentState = AppState::MAIN_SCREEN;
void reloadAll() {
    btnLed.Reload();
    lcdLed.Reload();
    gpsHandler.Reload();
    accelerometerHandler.Reload();
    instrumentDataModel.Reload();
    windHandler.Reload();
    Translator::SetLanguage(settings.GetValue<uint8_t>(SettingsKey::Language));
}

void sensorDisplayTask(void *pvParameters)
{
    //displayHandler.ResetDisplay();
    for (;;)
    {
        ButtonMessage buttonMessage;
        while (xQueueReceive(buttonEventQueue, &buttonMessage, 0) == pdTRUE)
        {
            handleButtonEvent(buttonMessage.name, buttonMessage.event);
            if (currentState == AppState::SETTINGS_SCREEN)
                break;
        }

        if (currentState == AppState::SETTINGS_SCREEN)
        {
            settingsDisplay.DrawSettingsUI(buttonEventQueue);
            reloadAll();
            currentState = AppState::MAIN_SCREEN;
        }
            displayHandler.UpdateDisplay();
            accelerometerHandler.ReadAccelerometerData();
            gpsHandler.UpdateGpsData();
            depthHandler.ReadPacket();
            windHandler.UpdateWindData();
        vTaskDelay(pdMS_TO_TICKS(settings.GetValue<int>(SettingsKey::DisplayScreenUpdate)));
    }
}

void handleButtonEvent(const ButtonName btnName, const ButtonEvent event)
{
    switch (event)
    {
    case ButtonEvent::SINGLE_CLICK:
        switch (btnName)
        {
        case ButtonName::BUTTON0:
            displayHandler.StepFocusedSensor();
            break;
        case ButtonName::BUTTON1:
            displayHandler.NextDisplayPage();
            break;
        case ButtonName::BUTTON3:
            currentState = AppState::SETTINGS_SCREEN;
            break;
        }
        break;
    case ButtonEvent::DOUBLE_CLICK:
        break;
    case ButtonEvent::LONG_PRESS:
        if (btnName == ButtonName::BUTTON0)
        {
            const bool newValue = !settings.GetValue<bool>(SettingsKey::LCDLedEnabled);
            settings.SetValue(SettingsKey::BtnLedEnabled, newValue);
            settings.SetValue(SettingsKey::LCDLedEnabled, newValue);
            btnLed.Reload();
            lcdLed.Reload();
        }
        break;
    case ButtonEvent::NONE:
    default:
        break;
    }
}

void setup()
{
    Serial.begin(115200);
    delay(1000); // Give serial a moment to wake up
    settings.Begin();

    Serial.println("Init PINs and SPI");
    pinMode(LIS3DH_CS, OUTPUT);
    digitalWrite(LIS3DH_CS, HIGH);
    pinMode(LCD_CS, OUTPUT);
    digitalWrite(LCD_CS, HIGH);

    SPI.begin(SPI_SCK, SPI_MISO, SPI_MOSI);

    Serial.println("Init Display");
    displayHandler.Init();
    Serial.println("Init Accelerometer");
    accelerometerHandler.Init();
    Serial.println("Init GPS");
    gpsHandler.Init();
    depthHandler.Begin();
    windHandler.Init();

    // Initialize buttons
    btn0.Begin();
    btn0.OnDoubleClick([]()
                                             { postButtonEvent(ButtonName::BUTTON0, ButtonEvent::DOUBLE_CLICK); });
    btn0.OnLongPress([]()
                                         { postButtonEvent(ButtonName::BUTTON0, ButtonEvent::LONG_PRESS); });
    btn0.OnSingleClick([]()
                                             { postButtonEvent(ButtonName::BUTTON0, ButtonEvent::SINGLE_CLICK); });
    btn1.Begin();
    btn1.OnDoubleClick([]()
                                             { postButtonEvent(ButtonName::BUTTON1, ButtonEvent::DOUBLE_CLICK); });
    btn1.OnLongPress([]()
                                         { postButtonEvent(ButtonName::BUTTON1, ButtonEvent::LONG_PRESS); });
    btn1.OnSingleClick([]()
                                             { postButtonEvent(ButtonName::BUTTON1, ButtonEvent::SINGLE_CLICK); });
    btn2.Begin();
    btn2.OnDoubleClick([]()
                                             { postButtonEvent(ButtonName::BUTTON2, ButtonEvent::DOUBLE_CLICK); });
    btn2.OnLongPress([]()
                                         { postButtonEvent(ButtonName::BUTTON2, ButtonEvent::LONG_PRESS); });
    btn2.OnSingleClick([]()
                                             { postButtonEvent(ButtonName::BUTTON2, ButtonEvent::SINGLE_CLICK); });
    btn3.Begin();
    btn3.OnDoubleClick([]()
                                             { postButtonEvent(ButtonName::BUTTON3, ButtonEvent::DOUBLE_CLICK); });
    btn3.OnLongPress([]()
                                         { postButtonEvent(ButtonName::BUTTON3, ButtonEvent::LONG_PRESS); });
    btn3.OnSingleClick([]()
                                             { postButtonEvent(ButtonName::BUTTON3, ButtonEvent::SINGLE_CLICK); });

        buttonEventQueue = xQueueCreate(16, sizeof(ButtonMessage));
        if (buttonEventQueue == nullptr)
        {
                Serial.println("Failed to create button event queue");
                return;
        }
    
    xTaskCreatePinnedToCore(
        sensorDisplayTask,
        "SensorTask",
        8192,
        NULL,
        1,
        NULL,
        0
    );

    xTaskCreatePinnedToCore(
        globalButtonTask,
        "ButtonManager",
        2048,
        NULL,
        2,
        NULL,
        1
    );

    btnLed.Begin();
    lcdLed.Begin();

    Serial.println("Setup complete, resetting display.");
}

void loop()
{

    vTaskDelay(pdMS_TO_TICKS(5000));
}

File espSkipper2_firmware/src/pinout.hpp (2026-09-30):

# ifndef PINOUT_HPP
# define PINOUT_HPP

#define SPI_SCK   12 // Shared with Display
#define SPI_MISO  13 // Used by LIS3DH
#define SPI_MOSI  11 // Shared with Display

#define LIS3DH_CS 10 // Dedicated CS for LIS3DH

#define GPS_RX_PIN 37
#define GPS_TX_PIN 36
#define GPS_FORCE_ON_PIN 35

#define WIND_RX_PIN  16  // Connects to SP3485 RX-I
#define WIND_TX_PIN  15  // Connects to SP3485 TX-O
#define WIND_RTS_PIN 6   // Connects to SP3485 RTS (Transmit/Receive Control)

#define LCD_CS 5
#define LCD_DC 9
#define LCD_RES 4

# endif

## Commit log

2026-06-28 initialized project with working code using all the sensors
2026-08-13 added ledhandler, buttonhandler and new display functions
2026-08-14 added rounding for accelerometer
2026-08-14 added led pwm
2026-08-14 fixed pwm not lighting up
    [ledHandler.cpp]
2026-08-14 improved button reliability
2026-08-15 fixed semaphore bugs on settingsPage
    [main.cpp]
2026-08-15 display high-speed flashing fix
    [Osptek_BWR_42.cpp, main.cpp]
2026-08-27 added lcd led
2026-09-01 added wind sensor, Now using textkey in datamondel unit instead title string
2026-09-02 fixed language string and unit conversion
    [settingsHandler.cpp]
2026-09-02 added option to enable/disable sensors in settings menu
2026-09-30 fixed accelerometer rounding with negative numbers, removed some unnecessare remaining comments
    [Osptek_BWR_42.cpp, accelerometerHandler.cpp]
2026-09-30 moved wind sensor pinout macro to pinout.hpp, renamed UART pinout macros
2026-09-30 added sensor state saving to preferences. Added helper functions to fetch the key strings for preferences
2026-09-30 using xQueue for button events, removing lock loginc from instrumentDataModel
2026-09-30 added readme and documentation resources added kicad pcb cad files
    [ESP32.kicad_sch, MICRO-USB-SMD_USB-MR-D-023.step, SMA-SMD_HYCW12-SMAW0863-1365B.step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]
